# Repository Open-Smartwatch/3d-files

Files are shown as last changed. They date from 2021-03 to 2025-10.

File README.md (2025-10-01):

# Open-Smartwatch 3D Files

How to read the folder names:

- first part:
  - light edition
  - light edition with round lipo
  - gps edition
- second part:
  - 0.8mm pcb
  - 1.6mm pcb
- third part:
  - 20mm pin wrist straps
  - 3d printed wrist straps

The case requires 10mm M2 hex screws. The printed straps require 6mm M2 hex screws.

## Sleek-Case 3D Files
Sleeker design made to be as compact and "watch like" as possible

Fits with 1.6mm light pcb and round battery
The battery and pcb need to be spaced using a round plastic piece cut from your usual transparent electronics packaging, should be around 0.3mm thick and same diameter as the pcb with a small cutout or flat spot for the battery wires.
The case requires 4 6mm M1.4 hex screws.

There will most likely be some sanding of the button's back face required for them to fit snugly and also not keep the button depressed. 30 seconds on 600 grit sandpaper should work

## Ultra-Thin 3D Files
Made because the sleek watch was still too bulky and wanted a smaller overall footprint.

This case has only been tested with the 1.6mm PCB and the round LiPo battery. You need 4 screws that seem to me M2 with a thread length of 2.5mm - the screws also need to be countersunk.

The buttons will also need to be modified to work - small amounts of sanding an snipping are required to make a unique button for each PCB button.

## Tools

The design files from *case* and *watch-faces* are made with [https://blender.org](https://blender.org).

The design files from *sleek-case* are made with SolidWorks.

The design files from *case-light-round-parametric* are made with OpenSCAD.

The design files from *ultra-thin* are made with Fusion360.

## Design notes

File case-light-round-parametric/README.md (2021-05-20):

# Open-Smartwatch OpenSCAD Files

The case can either use 10mm M2 hex screws, like the other designs, or 12mm M2 hex screws.
The printed straps required 6mm M2 hex screws, like the others.

If the preview in 'watch.scad' is too resource-intensive to work smoothly, set 'strap_radius' in 'strap.scad' to 0!

## Configuration

Settings that apply to all parts of the watch are defined in 'common.scad'.
You can of course modify these options, as well as ones from other files, as needed.

Use 'watch.scad' to either see the parts assembled, or generate an STL file for printing by setting 'view_assembly' to 'false'.

The text on top of the watchface is using the 'Droid Sans' font.
If this is not available on your system, you may want to select a different 'text_font' in 'top.scad' and adjust 'text-size' accordingly.

## Tools

The design files are made with [OpenSCAD](https://openscad.org/).
They have been made with version 2021.01 on Arch Linux.

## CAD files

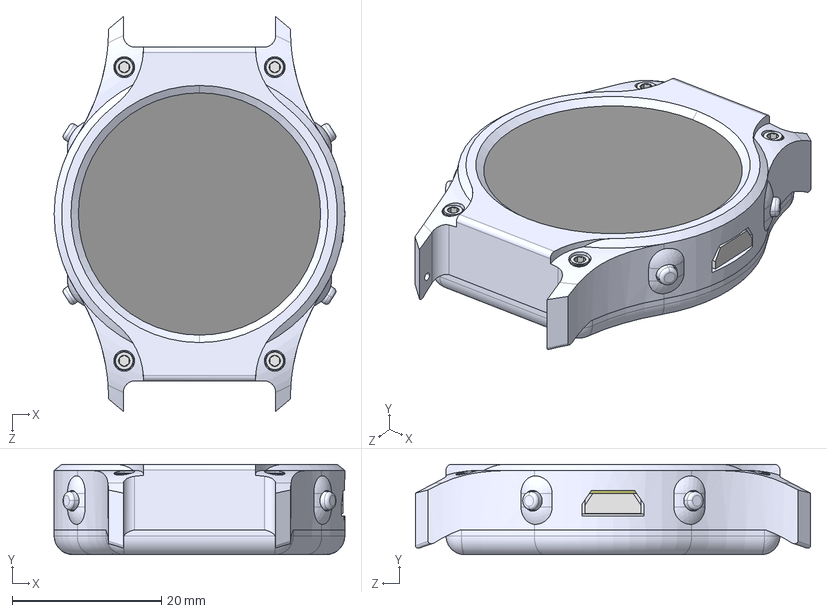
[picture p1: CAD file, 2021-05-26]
sleek-case-light-round-1.6mm-pcb-20mm-straps/sleek-case-light-round-1.6mm-pcb-20mm-straps-step-files/complete-watch.STEP
39.0 x 12.1 x 53.0 mm
watch_core
spacer
battery
case_top
button x 4
bottom
91292A332_18-8 STAINLESS STEEL SOCKET HEAD SCREW_91292A332 x 4

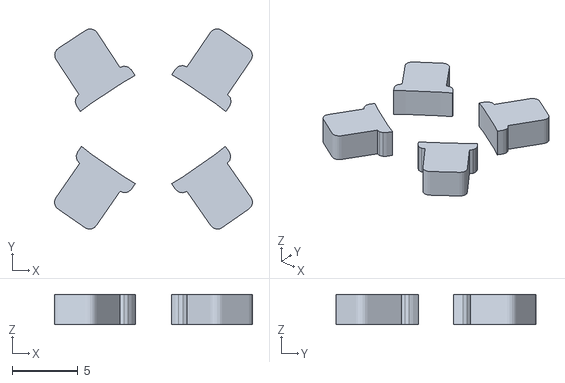
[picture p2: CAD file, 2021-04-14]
case-gps-0.8mm-pcb-20mm-straps/buttons-gps.stl
15.1 x 15.3 x 2.31

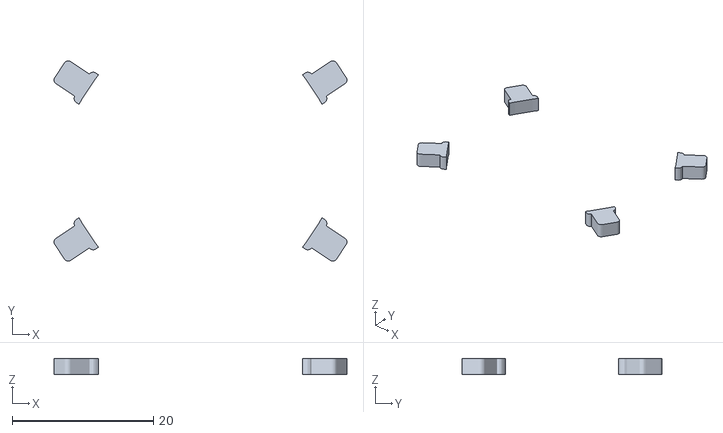
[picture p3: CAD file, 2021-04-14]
case-light-0.8mm-pcb-20mm-straps/case-light-0.8mm-pcb-20mm-straps-buttons-pla.stl
41.4 x 28.3 x 2.31

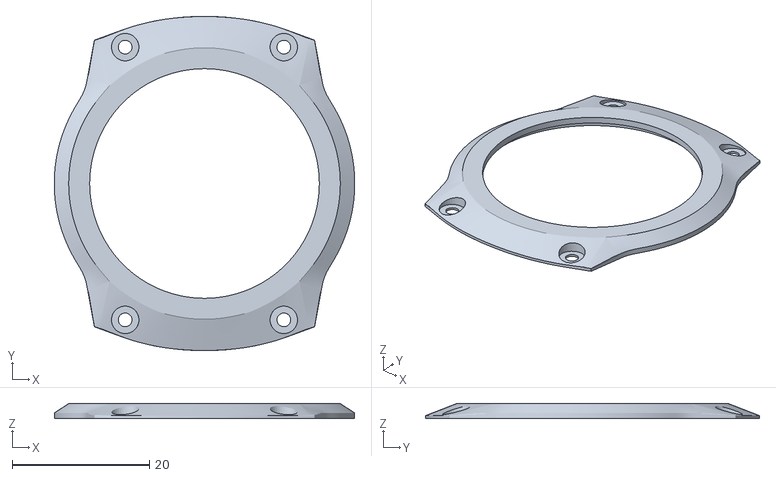
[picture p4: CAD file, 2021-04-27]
case-light-1.6mm-pcb-20mm-straps/case-light-1.6mm-pcb-20mm-straps-1-glass-pla.stl
43.7 x 48.6 x 2.18

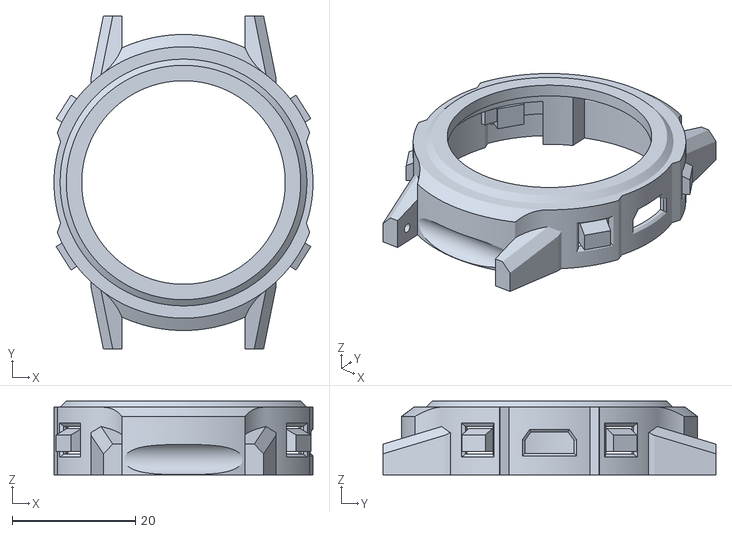
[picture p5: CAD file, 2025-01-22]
case-light-round-1.6mm-pcb-20mm-straps-coffeblock/case-top-light-round-1.6mm-pcb-20mm-straps-coffeblock.stl
42.0 x 54.0 x 12.0

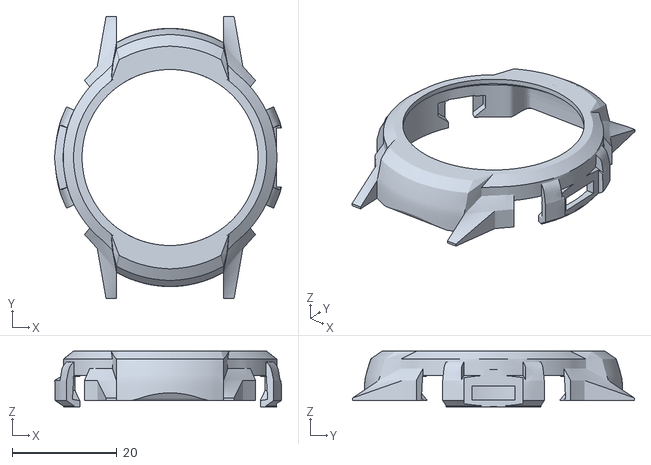
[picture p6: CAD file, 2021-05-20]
case-light-round-1.6mm-pcb-20mm-straps-flex-buttons/case-light-round-1.6mm-case-top.stl
43.4 x 54.0 x 10.7

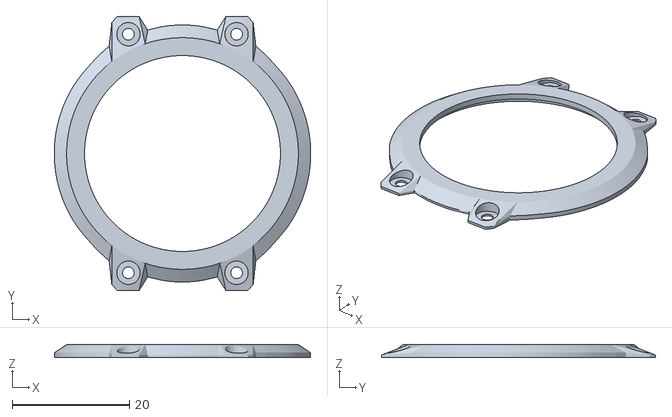
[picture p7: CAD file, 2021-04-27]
case-light-round-1.6mm-pcb-20mm-straps/case-light-round-1.6mm-pcb-20mm-straps-3-glass-pla.stl
43.7 x 46.7 x 2.18

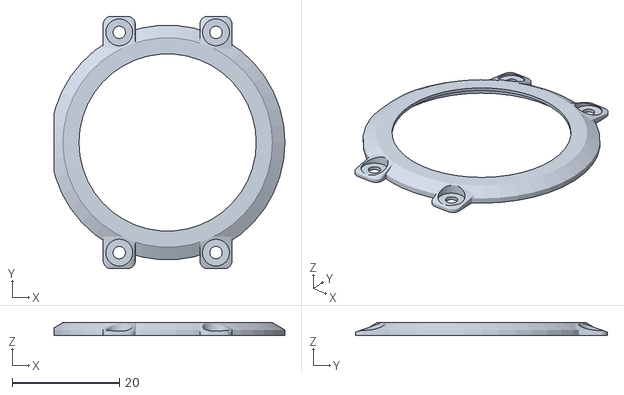
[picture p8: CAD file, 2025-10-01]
case-light-round-parametric/1.6mm_top.stl
43.0 x 47.0 x 2.40

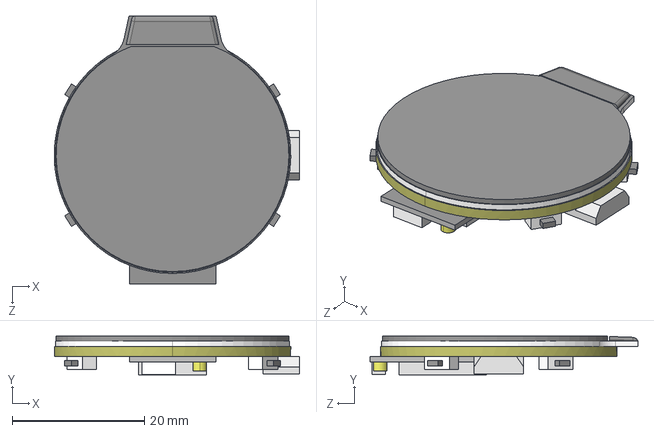
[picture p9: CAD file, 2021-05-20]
electronic-parts-light/watch_core.STEP
37.2 x 5.87 x 40.6 mm

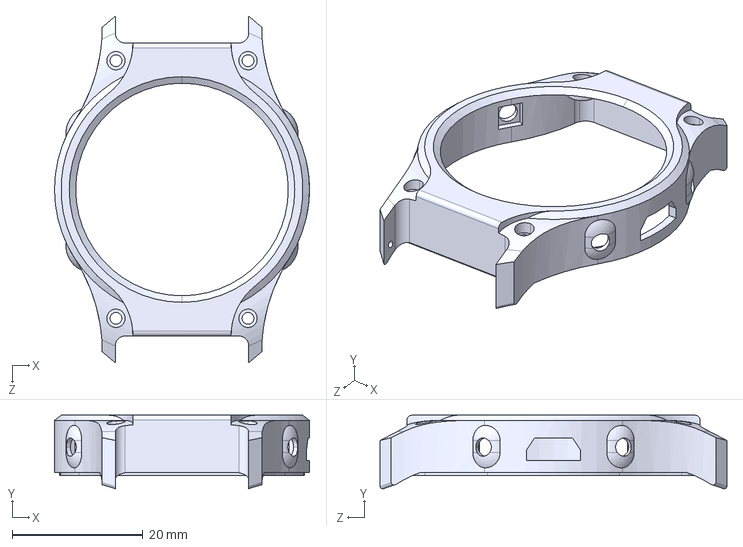
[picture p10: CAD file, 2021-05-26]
sleek-case-light-round-1.6mm-pcb-20mm-straps/sleek-case-light-round-1.6mm-pcb-20mm-straps-step-files/case_top.STEP
39.0 x 11.3 x 53.0 mm

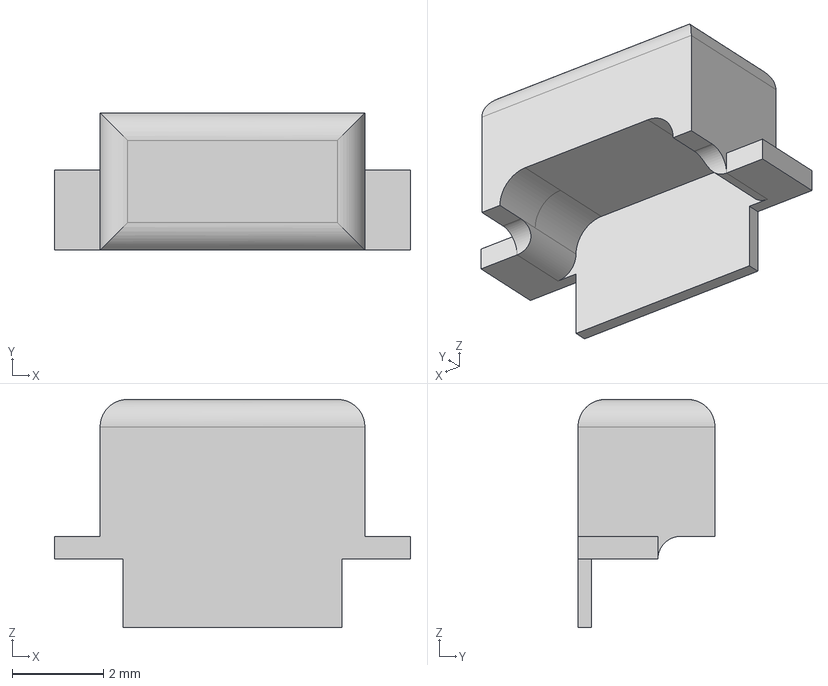
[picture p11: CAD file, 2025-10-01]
ultrathin-case-light-1.6mm-pcb-20mm-straps/Button.step
7.80 x 3.00 x 5.00 mm

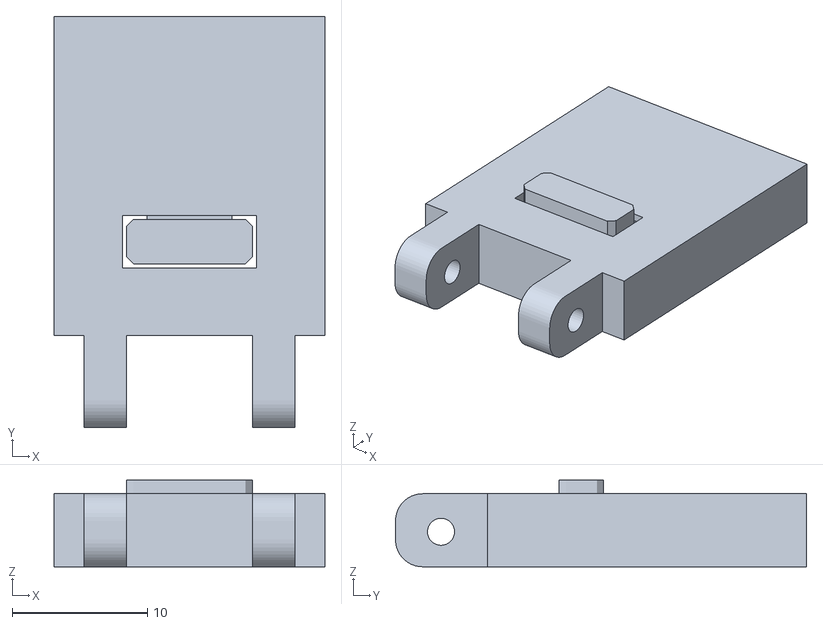
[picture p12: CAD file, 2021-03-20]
wrist-strap-linked/wrist-strap-linked-3-pla.stl
20.0 x 30.4 x 6.40

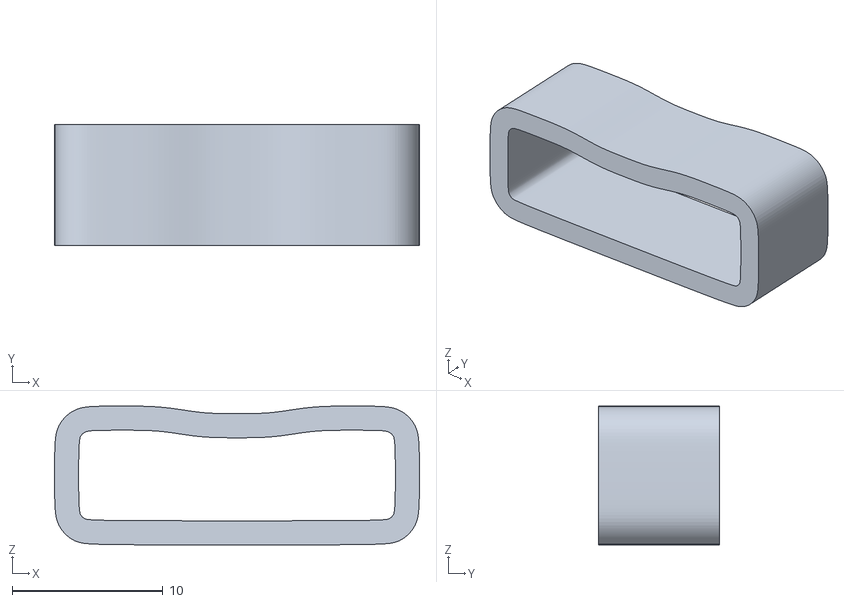
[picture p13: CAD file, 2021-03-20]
wrist-strap-tpu/wrist-strap-flex-3-pla.stl
24.2 x 8.00 x 9.20

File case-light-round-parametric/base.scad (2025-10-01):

include <common.scad>;

base_bottom = 1.5;
base_wall = 4.0;
base_screw_len_add = 0.4 + 0.3;

base_bat_dia = 35.5;
base_bat_cut_w = 22;
base_bat_cut_h = 3 + 1.5;
base_bat_cut_off = 0.9 - 1.5;

use_printed_strap = false;

base_strap_h = 7.8;
base_strap_d = 5.2 + base_strap_add_l;
base_strap_cyl = 3;
base_strap_warp = 1;
base_strap_cut = 0.1;
base_strap_off = body_radius;

fstrap_width = 20;
fstrap_dist = fstrap_width + 0.2;
fstrap_hole = 1.1;
fstrap_depth = 1.9;
fstrap_add = 1.5;
fstrap_h = base_strap_h - 2;
fstrap_warp = base_strap_warp - 1;

base_height = base_bottom + base_wall;

module base_bat(h) {
    difference() {
        cylinder(d = base_bat_dia, h = h);
        
        translate([-base_bat_dia / 2, -base_bat_dia + base_bat_cut_off, -1])
        cube([base_bat_dia, base_bat_dia / 2, h + 2]);
    }
    
    translate([-base_bat_cut_w / 2, -base_bat_dia / 2 + base_bat_cut_off, 0])
    cube([base_bat_cut_w, base_bat_cut_h, h]);
}

module base_strap() {
    translate([-base_strap_w / 2, 0, 0])
    difference() {
        hull() {
            cube([base_strap_w, 0.1, base_strap_h]);
            
            translate([0, base_strap_d - 0.1 - base_strap_cyl / 2, base_strap_h / 2 - 0.05 + base_strap_warp])
            rotate([0, 90, 0])
            cylinder(d = base_strap_cyl, h = base_strap_w);
        }
        
        translate([-1, base_strap_d - strap_d / 2, base_strap_h / 2 + base_strap_warp])
        rotate([0, 90, 0])
        screw(true, true);
        
        translate([-0.1, -0.1, -base_strap_off + base_height])
        cube([base_strap_w + 0.2, base_strap_cut + 0.1, base_strap_h]);
    }
}

module fstrap_piece(w, s) {
    translate([-w / 2, 0, 0])
    difference() {
        hull() {
            translate([0, -fstrap_add, 0])
            cube([w, 0.1 + fstrap_add, fstrap_h]);
            
            translate([0, base_strap_d - 0.1 - base_strap_cyl / 2, fstrap_h / 2 - 0.05 + fstrap_warp])
            rotate([0, 90, 0])
            cylinder(d = base_strap_cyl, h = w);
        }
        
        translate([-1, base_strap_d - strap_d / 2, fstrap_h / 2 + fstrap_warp])
        rotate([0, 90, 0])
        cylinder(d = s, h = w + 2);
        
        translate([-0.1, -0.1 - fstrap_add, -base_strap_off + base_height])
        cube([w + 0.2, base_strap_cut + 0.1 + fstrap_add, fstrap_h]);
    }
}

module fstrap() {
    for (i = [-1, 1])
    scale([i, 1, 1])
    translate([(fstrap_dist + fstrap_depth) / 2, 0, 0])
    fstrap_piece(fstrap_depth, fstrap_hole);
}

module base() {
    difference() {
        union() {
            body(base_bottom, true);
            
            translate([0, 0, base_bottom])
            body(base_wall, false);
            
            if (use_printed_strap)
            for (i = [-1, 1])
            scale([1, i, 1])
            translate([0, body_dia / 2 + base_mount_off, base_strap_off])
            base_strap();
            
            if (!use_printed_strap)
            for (i = [-1, 1])
            scale([1, i, 1])
            translate([0, body_dia / 2 + base_mount_off, base_strap_off])
            fstrap();
        }
        
        translate([0, 0, base_bottom - 0.01])
        base_bat(base_wall + 1.01);
        
        translate([0, 0, base_bottom - base_screw_len_add])
        base_screws();
        
        usb_flatten(base_height);
    }
}

//base();

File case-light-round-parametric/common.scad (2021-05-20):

pcb_h = 1.6;

body_dia = 43.7;
body_radius = 1.5;

mount_dist_w = 18.0;
mount_dist_h = 41.0;

face_mount_w = 6.0;
face_mount_d = face_mount_w;

base_mount_w = mount_dist_w + face_mount_w;
base_mount_d = 10;
base_mount_off = 1.65;

nut_dia = 1.9;
screw_dia = 2.3;
screw_gap = screw_dia - nut_dia;
screw_head_dia = 5.0;
screw_head_height = 2.3;

usb_flat = 0.7;

button_angle_off = 32.5;

button_angle_r = 90 + button_angle_off;
button_angle_1 = 90 - button_angle_off;
button_angle_2 = -90 + button_angle_off;
button_angle_3 = -90 - button_angle_off;

strap_d = 5;
strap_latch_ws = 3.3;
strap_latch_wl = 8.4;
base_strap_w = strap_latch_wl; //12.2;
base_strap_add_l = 0.3;

visualize_screws = false;
screw_visual_off = 5;
screw_len_body = 12;
screw_len_strap = 7.5;

$fn = 42;

module prism(l, w, h) {
    polyhedron(
        points = [[0,0,0], [l,0,0], [l,w,0], [0,w,0], [0,w,h], [l,w,h]],
        faces = [[0,1,2,3],[5,4,3,2],[0,4,5,1],[0,3,4],[5,2,1]]
    );
}

module usb_flatten(h) {
    translate([-body_dia / 2, -body_dia / 2, -1])
    cube([usb_flat, body_dia, h + 1.1]);
}

module roundedcylinder(d, h, r, top = false) {
    hull() // needed, otherwise rendering fails
    rotate_extrude(convexity = 10)
    translate([d / 2, 0, 0])
    rotate([0, 180, 0]) {
        if (top) {
            translate([0, r])
            square([d / 2, h - r * 2]);
        } else {
            translate([0, r])
            square([d / 2, h - r]);
        }
        
        //translate([r, 0])
        //square([d / 2 - r, r]);
        
        translate([r, r])
        circle(r = r);
        
        if (top) {
            translate([r, h - r])
            circle(r = r);
        
            //translate([r, h - r])
            //square([d / 2 - r, r]);
        }
    }
}

module roundedcube_side(x, y, z, r) {
    translate([r, r, 0])
    cube([x - r * 2, y - r * 2, z]);
    
    translate([r, 0, 0])
    cube([x - r * 2, y, z]);
    
    translate([0, r, 0])
    cube([x, y - r * 2, z]);
    
    translate([r, r, 0])
    cylinder(d = r * 2, h = z);
    
    translate([x - r, r, 0])
    cylinder(d = r * 2, h = z);
    
    translate([r, y - r, 0])
    cylinder(d = r * 2, h = z);
    
    translate([x - r, y - r, 0])
    cylinder(d = r * 2, h = z);
}

module roundedcube_bot_half(x, y, z, r) {
    translate([0, y, 0])
    rotate([90, 0, 0])
    linear_extrude(height = y) {
        translate([0, r])
        square([x, z - r]);
        
        translate([r, 0])
        square([x - r * 2, r]);
        
        translate([r, r])
        circle(r = r);
        
        translate([x - r, r])
        circle(r = r);
    }
}

module roundedcube_side_bot(x, y, z, r) {
    translate([0, r, 0])
    roundedcube_bot_half(x, y - r * 2, z, r);
    
    translate([x - r, 0, 0])
    rotate([0, 0, 90])
    roundedcube_bot_half(y, x - r * 2, z, r);
    
    translate([r, r, r])
    sphere(r = r);
    
    translate([x - r, r, r])
    sphere(r = r);
    
    translate([r, y - r, r])
    sphere(r = r);
    
    translate([x - r, y - r, r])
    sphere(r = r);
    
    translate([0, 0, r])
    roundedcube(x, y, z - r, r);
}

module roundedcube(x, y, z, r, round_bot = false, round_top = false) {
    if (!round_bot) {
        roundedcube_side(x, y, z, r);
    } else {
        if (round_top) {
            roundedcube_side_bot(x, y, z / 2, r);
            
            translate([0, y, z])
            rotate([180, 0, 0])
            roundedcube_side_bot(x, y, z / 2, r);
        } else {
            roundedcube_side_bot(x, y, z, r);
        }
    }
}

module screw_part(add, height = 0) {
    if (height == 0) {
        cylinder(d = screw_head_dia, h = 10);
        
        translate([0, 0, -20])
        cylinder(d = screw_dia + add, h = 21);
    } else {
        cylinder(d = screw_head_dia, h = screw_head_height);
        
        translate([0, 0, -height])
        cylinder(d = screw_dia + add, h = height + 1);
    }
}

module screw(nut = false, bottom = false, height = 20) {
    if (nut) {
        if (bottom) {
            translate([0, 0, height])
            screw_part(-screw_gap, height);
        } else {
            screw_part(-screw_gap, height);
        }
    } else {
        if (bottom) {
            translate([0, 0, height])
            screw_part(0, height);
        } else {
            screw_part(0, height);
        }
    }
}

module base_screws(nut = true, bottom = true) {
    for (i = [1, -1]) {
        for (j = [1, -1]) {
            translate([i * mount_dist_w / 2, j * mount_dist_h / 2, 0])
            screw(nut, bottom);
            
            if (visualize_screws) {
                %translate([i * mount_dist_w / 2 - screw_visual_off + 1, j * mount_dist_h / 2, 0])
                screw(nut, bottom);
            }
        }
    }
}

module body(h, rounded = false) {
    union() {
    if (rounded) {
        roundedcylinder(body_dia, h, body_radius);
    } else {
        cylinder(d = body_dia, h = h);
    }
    
    translate([-base_mount_w / 2, -body_dia / 2 - base_mount_off, 0])
    roundedcube(base_mount_w, base_mount_d, h, body_radius, rounded);

    scale([1, -1, 1])
    translate([-base_mount_w / 2, -body_dia / 2 - base_mount_off, 0])
    roundedcube(base_mount_w, base_mount_d, h, body_radius, rounded);
    }
}

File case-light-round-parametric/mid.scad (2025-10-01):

include <common.scad>;

use_single_piece_buttons = false;

lcd_parts_height = 4.3;
electronics_height = lcd_parts_height + pcb_h;

mid_base = 0.8;
electronics_dia = 37.3;
cut_w = 7.0;
cut_h = 38.0;
cut_tw = 14.5;
cut_th = 4.5;
cut_off = 1;

top_cut_w = 14.6;
top_cut_l = 3.0;
top_cut_off = 1.6; //2.0;
bot_cut_w = 15.8;
bot_cut_l = 4.2;
bot_cut_off = 2.3; //0.5;
bot_cut_wall_h = pcb_h + 0.2; //1.8;
bot_cut_wall_w = 1.2;

usb_w = 8.3;
usb_h = 3.8;
usb_cut = 8.5;
usb_cut_off = 0.7;
usb_cut_len = 1.6;

mid_strap_cut_w = 10;
mid_strap_cut_h = 5;
mid_strap_cut_d = mid_strap_cut_h - 1;
mid_strap_cut_off_y = 1.1;
mid_strap_cut_off_z = 0.5;

mid_button_width = 4.3 - 0.3;
mid_button_height = 3.0;
mid_button_depth = 4.0;
mid_button_gap_width = 2.6;
mid_button_gap_wall = 1.6;
mid_button_off = 0;//0.25; //1.3; //pcb_h - 0.3;
mid_button_holder_width = 5.4;
mid_button_holder_depth = 1.4;

button_height = 2.2;
button_length = 5.0;
button_width = 3.7;
button_radius = 0.5;
button_wing = 0.5;
button_wing_len = 1.0;

mid_snap_dia = 2 + 0.2;
mid_snap_off = 2.55;

mid_threshold = 4.0;

mid_height = mid_base + electronics_height;

module mid_cutout(h) {
    translate([-cut_w / 2, -cut_h / 2, 0])
    linear_extrude(h) {
        square([cut_w, cut_h]);
        
        translate([-(cut_tw - cut_w) / 2, cut_h - cut_th])
        square([cut_tw, cut_th]);
    }
}

module mid_button_cut_original() {
    translate([-mid_button_width / 2, -1, 0])
    cube([mid_button_width, mid_button_depth + 2, mid_button_height]);
    
    translate([-mid_button_holder_width / 2, (body_dia - electronics_dia) / 2 - mid_button_holder_depth, 0])
    cube([mid_button_holder_width, mid_button_holder_depth + 1, mid_button_height]);
    
    translate([-mid_button_gap_width / 2, mid_button_gap_wall, mid_button_height - 1])
    cube([mid_button_gap_width, mid_button_depth - mid_button_gap_wall + 1, mid_height]);
}

module mid_button_original() {
    translate([button_width + button_wing, 0, button_length])
    rotate([0, 180, 0])
    roundedcube(button_width, button_height, button_length, button_radius, true);
    
    cube([button_wing + button_radius, button_height, button_wing_len]);
    
    translate([button_width, 0, 0])
    cube([button_wing + button_radius, button_height, button_wing_len]);
}

module mid_buttons_original() {
    for (i = [button_angle_r, button_angle_1, button_angle_2, button_angle_3]) {
        rotate([0, 0, i])
        translate([-button_width / 2 - button_wing, -body_dia / 2 + button_length - button_wing_len, button_height])
        rotate([90, 0, 0])
        mid_button_original();
    }
}

module buttons_cutouts() {
    if (use_single_piece_buttons) {
        // TODO
    } else {
        mid_button_cut_original();
    }
}

module buttons_print() {
    if (use_single_piece_buttons) {
        // TODO
    } else {
        translate([button_height, 0, 0])
        rotate([0, 0, 90])
        mid_button_original();
        
        translate([button_height * 2 + 2, 0, 0])
        rotate([0, 0, 90])
        mid_button_original();
        
        translate([button_height * 3 + 4, 0, 0])
        rotate([0, 0, 90])
        mid_button_original();
        
        translate([button_height * 4 + 6, 0, 0])
        rotate([0, 0, 90])
        mid_button_original();
    }
}

module buttons_assembly() {
    if (use_single_piece_buttons) {
        // TODO
    } else {
        mid_buttons_original();
    }
}

module mid_body_cut_2() {
    translate([-mid_strap_cut_w / 2, -body_dia / 2 - 7, mid_height - 5])
    rotate([45, 0, 45])
    cube([5, 10, 1]);
}

module mid_body_cut() {
    translate([-mid_strap_cut_w / 2, -body_dia / 2 + mid_strap_cut_off_y, mid_height + mid_strap_cut_off_z])
    rotate([180, 0, 0])
    prism(mid_strap_cut_w, mid_strap_cut_d, mid_strap_cut_h);
    
    mid_body_cut_2();
    
    scale([-1, 1, 1])
    mid_body_cut_2();
}

module mid_body() {
    difference() {
        body(mid_height);
        
        mid_body_cut();
        
        scale([1, -1, 1])
        mid_body_cut();
    }
    
    translate([0, 0, mid_height - 1])
    cylinder(d = body_dia, h = 1);
}

module mid() {
    difference() {
        mid_body();
        
        rotate([0, 0, 180])
        translate([0, -cut_off, -1])
        mid_cutout(mid_base + 2);
        
        translate([-body_dia / 2 - 1, -usb_w / 2, mid_base])
        cube([body_dia / 2, usb_w, usb_h]);
        
        translate([-usb_cut_len - body_dia / 2 + (body_dia - electronics_dia) / 2 + usb_cut_off, -usb_cut / 2, mid_base])
        cube([usb_cut_len, usb_cut, mid_height]);
        
        usb_flatten(mid_height);
        
        for (i = [button_angle_r, button_angle_1, button_angle_2, button_angle_3]) {
            rotate([0, 0, i])
            translate([0, -body_dia / 2, mid_base + mid_button_off])
            buttons_cutouts();
        }
        
        translate([0, 0, -1])
        base_screws(false, true);
        
        translate([0, 0, mid_base]) {
            cylinder(d = electronics_dia, h = mid_height - mid_base + 1);
            
            translate([-top_cut_w / 2, electronics_dia / 2 - top_cut_off, 0])
            cube([top_cut_w, top_cut_l, mid_height - mid_base + 1]);
            
            translate([-bot_cut_w / 2, -electronics_dia / 2 - bot_cut_off, 0])
            difference() {
                cube([bot_cut_w, bot_cut_l, mid_height - mid_base + 1]);
                
                translate([-1, -1, -1])
                cube([bot_cut_w + 2, bot_cut_wall_w + 1, mid_height - mid_base - bot_cut_wall_h + 1]);
            }
        }
    }
    
    rotate([0, 0, -135 - 10])
    translate([0, -body_dia / 2 + mid_snap_off, mid_base])
    cylinder(d = mid_snap_dia, h = mid_height - mid_base);
    rotate([0, 0, -45 + 10])
    translate([0, -body_dia / 2 + mid_snap_off, mid_base])
    cylinder(d = mid_snap_dia, h = mid_height - mid_base);
    rotate([0, 0, 135 + 10])
    translate([0, -body_dia / 2 + mid_snap_off, mid_base])
    cylinder(d = mid_snap_dia, h = mid_height - mid_base);
    rotate([0, 0, 45 - 10])
    translate([0, -body_dia / 2 + mid_snap_off, mid_base])
    cylinder(d = mid_snap_dia, h = mid_height - mid_base);
}

module mid_assembly() {
    mid();

    color("red")
    buttons_assembly();
}

//mid_assembly();
//mid();
//buttons_print();

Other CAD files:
sleek-case-light-round-1.6mm-pcb-20mm-straps/sleek-case-light-round-1.6mm-pcb-20mm-straps-top.STL
case-light-round-parametric/strap.scad
case-gps-0.8mm-pcb-20mm-straps/case-gps-bot.stl
case-gps-0.8mm-pcb-20mm-straps/case-gps-mid.stl
case-gps-0.8mm-pcb-20mm-straps/case-gps-top.stl
case-light-0.8mm-pcb-20mm-straps/case-light-0.8mm-pcb-20mm-straps-1-pla.stl
case-light-0.8mm-pcb-20mm-straps/case-light-0.8mm-pcb-20mm-straps-2-pla.stl
case-light-0.8mm-pcb-20mm-straps/case-light-0.8mm-pcb-20mm-straps-3-pla.stl
case-light-0.8mm-pcb-20mm-straps/case-light-0.8mm-pcb-20mm-straps.blend
case-light-0.8mm-pcb-printed-straps/case-light-0.8mm-pcb-printed-straps-1-pla.stl
case-light-0.8mm-pcb-printed-straps/case-light-0.8mm-pcb-printed-straps-2-pla.stl
case-light-0.8mm-pcb-printed-straps/case-light-0.8mm-pcb-printed-straps-3-pla.stl
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

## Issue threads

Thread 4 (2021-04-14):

buttons on case-light-round-1.6mm-pcb-printed-straps

targor, 2021-04-14:
Are there any printable buttons for case-light-round-1.6mm-pcb-printed-straps? Or do i get something wrong here?

uvwxy, 2021-04-14:
I added all the missing button files, in your example:

https://github.com/Open-Smartwatch/3d-files/blob/master/case-light-round-1.6mm-pcb-printed-straps/case-light-round-1.6mm-pcb-printed-straps-buttons-pla.stl

targor, 2021-04-16:
thank you so much :)  👍 .

Closed 2021-04-14.

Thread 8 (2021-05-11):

Per case based readym

xasz, 2021-05-11:
I think there sould be a per case based readme with:
What you need (Screws, Glue, ... )?
Some print tipps?
Short assembly? ( For example where does the glass go)

xasz, 2021-05-11:
Good idea from matti04, if possible:

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

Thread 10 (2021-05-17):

0.8mm pcb round battery 20mm watch strap design

smb1985, 2021-05-17:
Hi, it would be great to see a design for a 0.8mm pcb with a round battery and a standard 20mm watch strap. I think this particular combo isn't represented yet

uvwxy, 2021-05-20:
Does anyone have the time to resolve #11 #12 #13 with this ticket by creating this case in open scad and including the comments from @MarkJeronimus ?

Currently, I don't have the time for this (even if I would like to learn OpenScad)

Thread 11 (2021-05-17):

STL files incompatible with OpenSCAD

MarkJeronimus, 2021-05-17:
The STL files have 'merged' components, as opposed to 'union-ed'. Since STL is just a 'bunch of separate triangles', all geometrical clues about this situation are lost, and this causes them to be unable to be used with the CGAL library in OpenSCAD (used for exporting). There's no workaround or possible fix for this.

For example, If I slice this stl in half through the center line, I see this 'box' intersecting, but not interacting with, the rest of the case.

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

Through the 'hole' that's not supposed to be there, you see rogue faces (because the preview doesn't know how to handle two front faces or two back faces in direct succession)

Long thread about STL difficulties (not exactly this issue, but something related): http://forum.openscad.org/Model-Not-rendering-CGal-error-td22122.html
Also, some slicers will do wrong things, as explained here: https://www.afaik.at/post/mergeopenscad/

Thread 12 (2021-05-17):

No STL files for light edition PCB 1mm

MarkJeronimus, 2021-05-17:
I bought two light editions from Lilygo via AliExpress, and the PCB they use is 1.0mm, not 0.8 or 1.6mm. I could probably squeeze the module into the case but I don't like unnecessary forces.

I have simulated this in OpenSCAD and I find the thickness for the PCB+DISPLAY is 2.8mm, and I measure with my calipers that my item is 2.86mm (excluding screen protector). I can squeeze my calipers such that the gap between the display and PCB disappears, and I measure 2.78mm, but if I do that all around, the display will probably bulge because of the double-sided tape in between pushing them apart by ~0.2mm. (the piece of tape is small, like 1x2cm)

uvwxy, 2021-05-20:
I have no influence on which pcb thickness they chose. As I have built & soldered mine based on 0.8mm and 1.6mm PCBs these are the only I have made so far.

The best approach would be a parameterised case based on open scad. See this for a start: https://github.com/Open-Smartwatch/3d-files/tree/master/case-light-round-parametric-printed-straps

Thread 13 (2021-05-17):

The display flex ribbon extends more than the case allows for

MarkJeronimus, 2021-05-17:
The Light Edition watch I have doesn't fit (without squeezing) into the case.

I measure that the case allows for a 38.8mm total dimension from the very top of the display (i.e. 18.0mm above the optical center) to the bottom-most extend of the cavity for the flex. When I measure my item, the round display is exactly 36.0mm wide (just as a verifying measure to show that I don't measure wrong) and the total height is 39.5mm. This is 0.7mm too much. Given that the bend radius of the flex is about 0.75mm, this is no small issue. It _could_ probably fit, but it would seriously hurt the flex by squeezing it into a square shape with bend radii way too small.

This is a rendering of the STL file, along with a model of the electronics according to my measurements:

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

Note that the cavity for the flex also seems too shallow, as my flex measures about 1.95mm in thickness (in the model I used 2mm, at line 20)

uvwxy, 2021-05-20:
Best approach to fix this would be with the parameterised model: https://github.com/Open-Smartwatch/3d-files/tree/master/case-light-round-parametric-printed-straps

ShandilyaSolutions, 2021-09-18:
what if the case itself is designed by subtracting the dimensions of the pcb?  If provided with all the necessary data and dimensions, I can provide an elegant solution for this problem without falling in the need of all parameterized modelling. (Finger Crossed)

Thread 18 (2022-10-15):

Aluminium case

jessp01, 2022-10-15:
Hello all,

I was thinking of using the https://github.com/Open-Smartwatch/3d-files/tree/master/case-light-1.6mm-pcb-20mm-straps STLs to produce an aluminium case but I am a bit concerned about it interfering with the BT and WIFI signals.
Of course, many smartwatch cases have parts made of aluminium/stainless steel but the bottom is typically made of a different material (ABS/plastic).

I suppose I have a two part question:
- Assuming I take the above design as is and produce all parts using aluminium, do you reckon it will interfere with the signal?
- If so, has anyone created a different design where the top frame and sides are separate (and can therefore be aluminium) from the bottom (that can be made of a different material that will not interfere with the signal)? Such a design will also be less expensive to produce..

Thanks in advance for any pointers,

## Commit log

2020-09-02 version 0.1.1-dev
    [avata.SLDASM, plexyglass 1x39mm.AMF, plexyglass 1x39mm.IGS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]
2020-09-03 initial blender version
    [v1.0.blend]
2020-10-11 add watchfaces
    [simple-01.blend]
2020-11-09 minify blend file by 90%, latest design
    [simple-01.blend, v1.0-bot.stl, v1.0-btn.stl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]
2020-11-11 refactor repository
    [avata.SLDASM, plexyglass 1x39mm.AMF, plexyglass 1x39mm.IGS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]
2020-11-11 change render settings
    [v1.0.blend]
2021-01-02 add light edition
    [block-button-support.stl, enforce-support.stl, osw-light-bot.stl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]
2021-01-05 light: update mid element
    [osw-light-mid.stl, osw-light.blend]
2021-01-08 update light case
    [osw-buckle-1.stl, osw-buckle-2.stl, osw-light.blend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]
2021-01-08 light: structure scene collectiuons
    [osw-light.blend]
2021-01-10 add new link stl, add logo render
    [osw-light-chain-links.stl, osw-light-clasp2-a.stl, osw-light-clasp2-b.stl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]
2021-01-11 add part 5
    [osw-light-strap-part-1.stl, osw-light-strap-part-2.stl, osw-light-strap-part-3.stl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]
2021-02-12 add latst files
    [case-gps.blend, osw-light-round-lipo-bot.stl, osw-light-round-lipo-mid.stl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]
2021-02-15 add 20mm prototype
    [case-gps.blend, osw-light-20mm-bot.stl, osw-light-20mm-straps.blend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]
2021-03-20 cleanup all files
    [block-button-support.stl, case-gps-bot.stl, case-gps-mid.stl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]
2021-03-20 cleanup round lipo files
    [case-light-round-0.8mm-pcb-printed-straps-1-pla.stl, case-light-round-0.8mm-pcb-printed-straps-2-pla.stl, case-light-round-0.8mm-pcb-printed-straps-3-pla.stl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]
2021-03-21 fix 0.8mm light cases
    [case-light-0.8mm-pcb-20mm-straps-1-pla.stl, case-light-0.8mm-pcb-20mm-straps-2-pla.stl, case-light-0.8mm-pcb-20mm-straps.blend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]
2021-03-21 fix light round 0.8mm
    [case-light-round-0.8mm-pcb-printed-straps-1-pla.stl, case-light-round-0.8mm-pcb-printed-straps-2-pla.stl, case-light-round-0.8mm-pcb-printed-straps.blend]
2021-03-25 add logo2.blend
    [logo2.blend]
2021-03-28 logo attempt no 2
    [logo2.blend]
2021-03-30 add case-light-round-1.6mm-pcb-20mm-straps-flex-buttons/
    [case-light-round-1.6mm-case-bot.stl, case-light-round-1.6mm-case-top.stl, case-light-round-1.6mm-flex-bot.stl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]
2021-04-03 minor fixes on light square cases
    [case-light-0.8mm-pcb-20mm-straps-2-pla.stl, case-light-0.8mm-pcb-20mm-straps.blend, case-light-0.8mm-pcb-printed-straps-2-pla.stl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]
2021-04-05 case-light-round-1.6mm-flex: enable mirror modifier
    [case-light-round-1.6mm-flex.blend]
2021-04-05 case-light-round-1.6mm-flex: add buttons.stl
    [buttons.stl]
2021-04-06 improve buttons on latest flex/solid design
    [case-light-round-1.6mm-flex.blend]
2021-04-08 add sapphire glass to round flex case
    [case-light-round-1.6mm-case-top.stl, case-light-round-1.6mm-flex.blend]
2021-04-13 add cnc variant, fix normals
    [case-light-round-1.6mm-case-bot.stl, case-light-round-1.6mm-case-top-cnc.stl, case-light-round-1.6mm-case-top.stl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]
2021-04-14 Added stl file for GPS edition buttons
    [buttons-gps.stl]
2021-04-14 add missing button files, remove stale files
    [avata.SLDASM, case-light-0.8mm-pcb-20mm-straps-buttons-pla.stl, case-light-0.8mm-pcb-printed-straps-buttons-pla.stl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]
2021-04-23 add case-light-round-1.6mm-pcb-20mm-straps/
    [case-light-round-1.6mm-pcb-20mm-straps-1-pla.stl, case-light-round-1.6mm-pcb-20mm-straps-2-pla.stl, case-light-round-1.6mm-pcb-20mm-straps-3-pla.stl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]
2021-04-25 fix export middle piece of case-light-round-1.6mm-pcb-20mm-straps
    [case-light-round-1.6mm-pcb-20mm-straps-2-pla.stl, case-light-round-1.6mm-pcb-20mm-straps.blend]
2021-04-27 add alternative top files with glass cutout
    [case-light-1.6mm-pcb-20mm-straps-1-glass-pla.stl, case-light-1.6mm-pcb-20mm-straps.blend, case-light-1.6mm-pcb-printed-straps-1-glass-pla.stl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]
2021-05-03 lugless model
    [LuglessOpenSmartwatch_BatteryCompartment.stl, LuglessOpenSmartwatch_CompartmentBuffer.stl, LuglessOpenSmartwatch_Upper.stl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]
2021-05-03 including .obj files and .f3d files
    [LuglessOpenSmartwatch_Parameterized_WiderScrewSpacing v37.f3d, LuglessOpenSmartwatch_Parameterized_WiderScrewSpacing v37.obj, LuglessOpenSmartwatch_RoundButton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]
2021-05-05 first steps for parametric light-round case. strap, mid, bottom still unfinished.
    [base.scad, common.scad, mid.scad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]
2021-05-06 further work on openscad model. moved stuff into common. added usb flattening everywhere. add cutouts and buttons to mid section. add base strap mount. add text to face.
    [base.scad, common.scad, mid.scad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]
2021-05-06 Work on parametric design. Added readme, buttons, screw visualization.
    [base.scad, common.scad, mid.scad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]
2021-05-08 adjusted parametric design after some test prints
    [base.scad, common.scad, mid.scad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]
2021-05-08 added parametric stl files
    [1.6mm_base.stl, 1.6mm_buttons.stl, 1.6mm_mid.stl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]
2021-05-20 increase glass cutout for FDM tolerances
    [case-light-round-1.6mm-case-top.stl, case-light-round-1.6mm-flex.blend]
2021-05-20 rename directory
    The OSW githubio page shows the listing for the PCB as 1.6mm
    [LuglessOpenSmartwatch_BatteryCompartment.stl, LuglessOpenSmartwatch_CompartmentBuffer.stl, LuglessOpenSmartwatch_Parameterized_WiderScrewSpacing v37.f3d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]
2021-09-02 Create ultrathin-case-light-1.6mm-pcb-20mm-straps
2021-09-05 [parametric] support 20mm straps. some tweaks.
    [1.6mm_base.stl, 1.6mm_base_printed_strap.stl, 1.6mm_buttons.stl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]
2021-09-05 [parametric] rename folder, no longer supports printed-straps only.
    [1.6mm_base.stl, 1.6mm_base_printed_strap.stl, 1.6mm_buttons.stl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]
2025-01-22 new file: case-light-round-1.6mm-pcb-20mm-straps-coffeblock/case-bottom-light-round-1.6mm-pcb-20mm-straps-coffeblock.stl new file: case-light-round-1.6mm-pcb-20mm-straps-coffeblock/case-light-round-1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
    [case-bottom-light-round-1.6mm-pcb-20mm-straps-coffeblock.stl, case-light-round-1.6mm-pcb-20mm-straps-coffeblock.f3z, case-top-light-round-1.6mm-pcb-20mm-straps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]
